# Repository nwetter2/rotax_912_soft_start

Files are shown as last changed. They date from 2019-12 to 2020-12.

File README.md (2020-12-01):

# rotax_912_soft_start
Soft start ignition module for Rotax 900 series engines

All parts [listed in BOM](https://github.com/nwetter2/rotax_912_soft_start/blob/master/BOM.pdf).

Older versions of the Rotax 900 series engines are prone to kickback on starting, which is violent and damaging to the engine. This project, inspired by a similar project by [Turbo-Tom at Rotary Wing Forums](https://www.rotaryforum.com/threads/soft-start-unit-for-rotax-912uls.23381/), improves the issue by ensuring retarded timings are used during start. It accomplishes this by using a relay to introduce a diode in parallel with the timing coil, which filters out the advanced timing pulse, which is opposite the polarity of the retarded timing pulse. Note that Turbo-Tom's design introduces the diode in series with the coil, and this did not work in testing by this project.

The design is quite simple and uses through-hole components to ease construction. It uses the same connectors as the Rotax ignition system, so one can simply unplug one ignition module and insert the soft start module between it and the timing coils. Then, the disable wire of the opposite ignition module is connected, allowing the unmodified ignition circuit to be disabled during start. The mod is also connected to the starter relay and this is what engages the relays during start. A capacitor keeps the relays engaged for 3-8 seconds after starting. Lastly, there is an optional connection for an external indicator, which will be connected to ground while the module is active and left floating when not.

The enclosure is bolted to the top of the existing ignition modules, using longer M5 bolts and washers. The enclosure needs to be modified to accept the larger diameter bolts, and holes added for the wires to pass through. It is recommended to waterproof the pcb after assembly, using the silicone conformal coat listed in the BOM. Loctite 221 or 222 should be used on the mounting bolts.

## Schematic

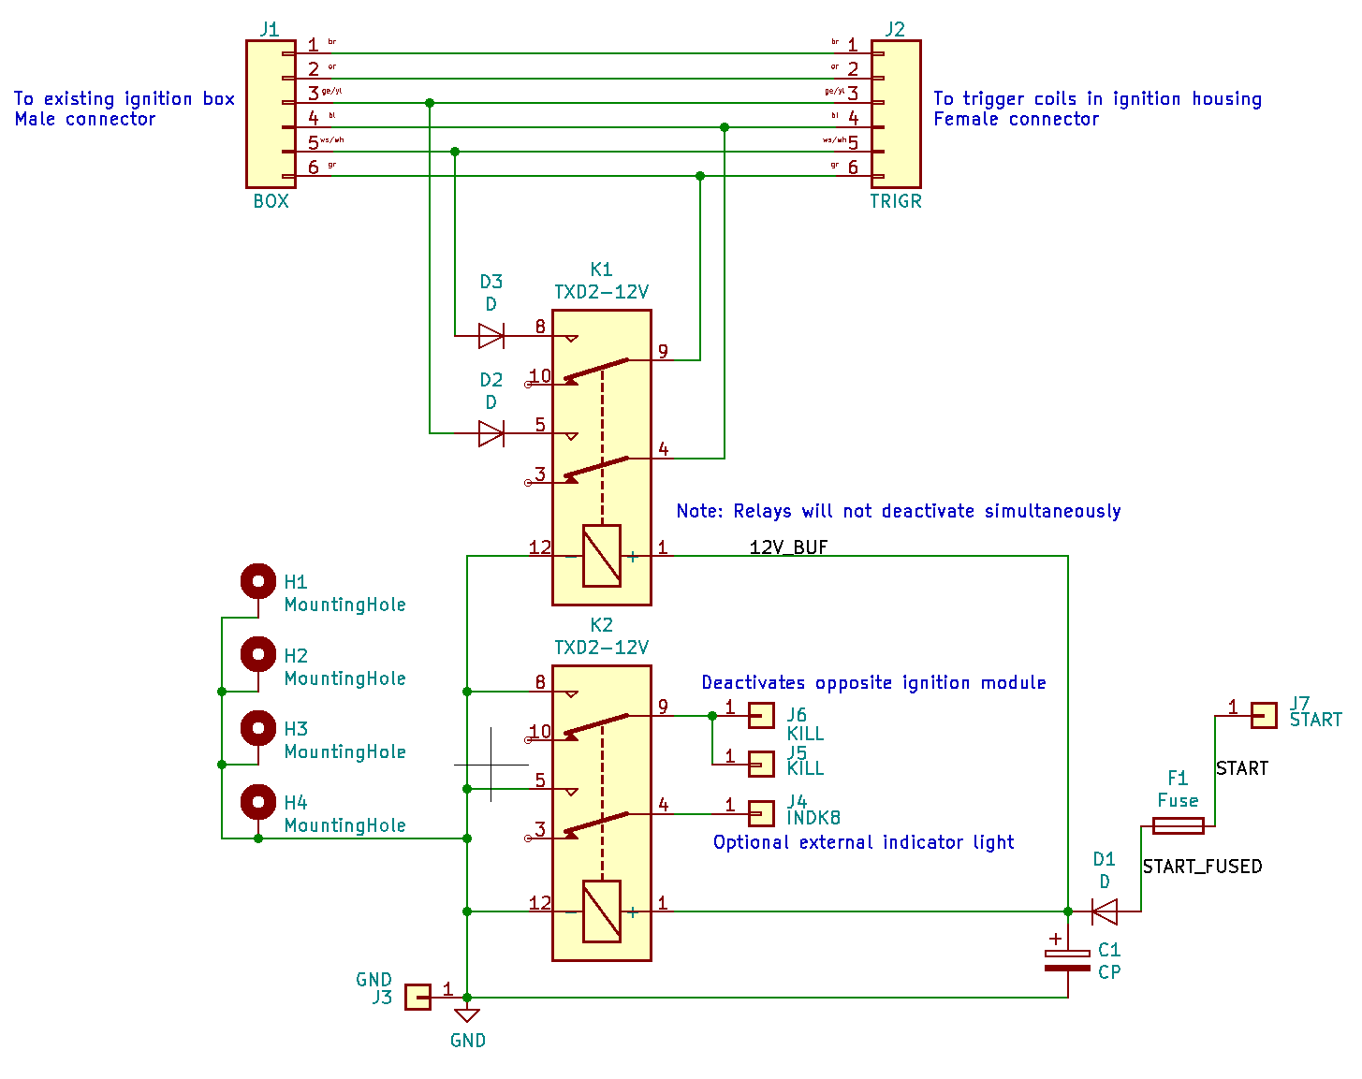
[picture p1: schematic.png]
schematic


## Front

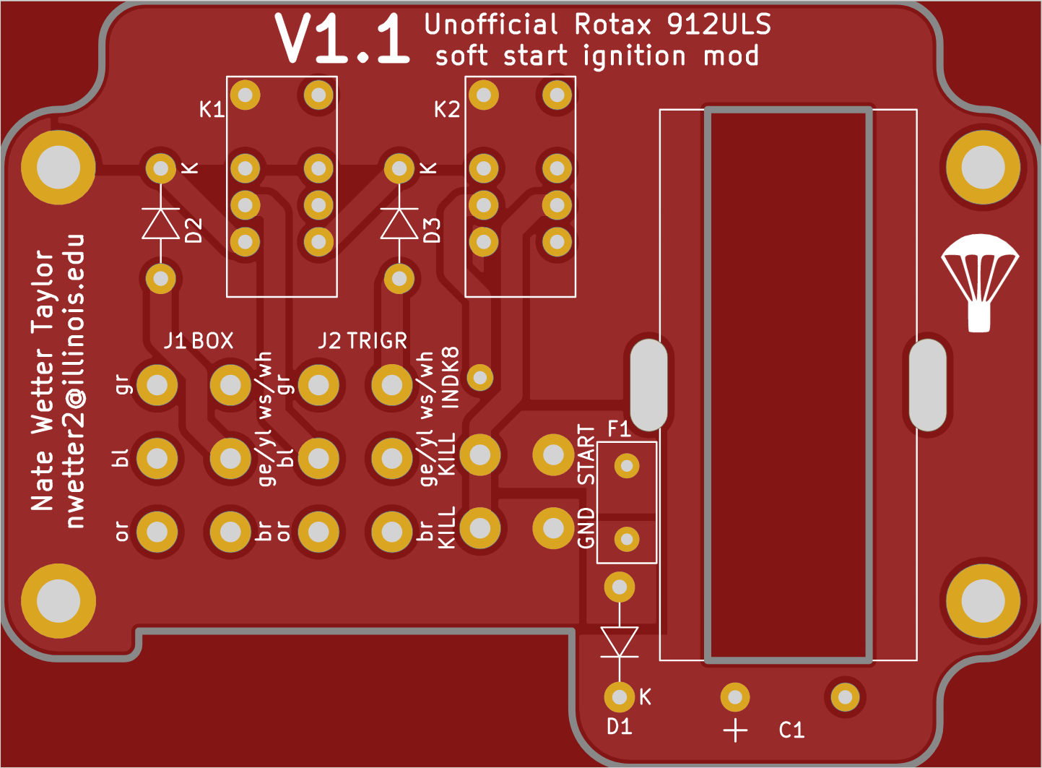
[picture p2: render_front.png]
front


## Back

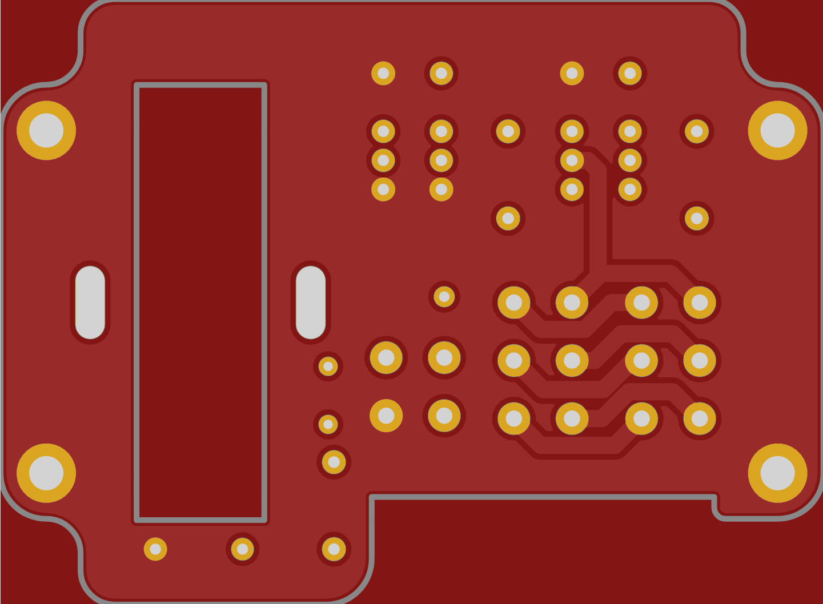
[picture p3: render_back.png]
back


## Assembled
V1.0; no cover

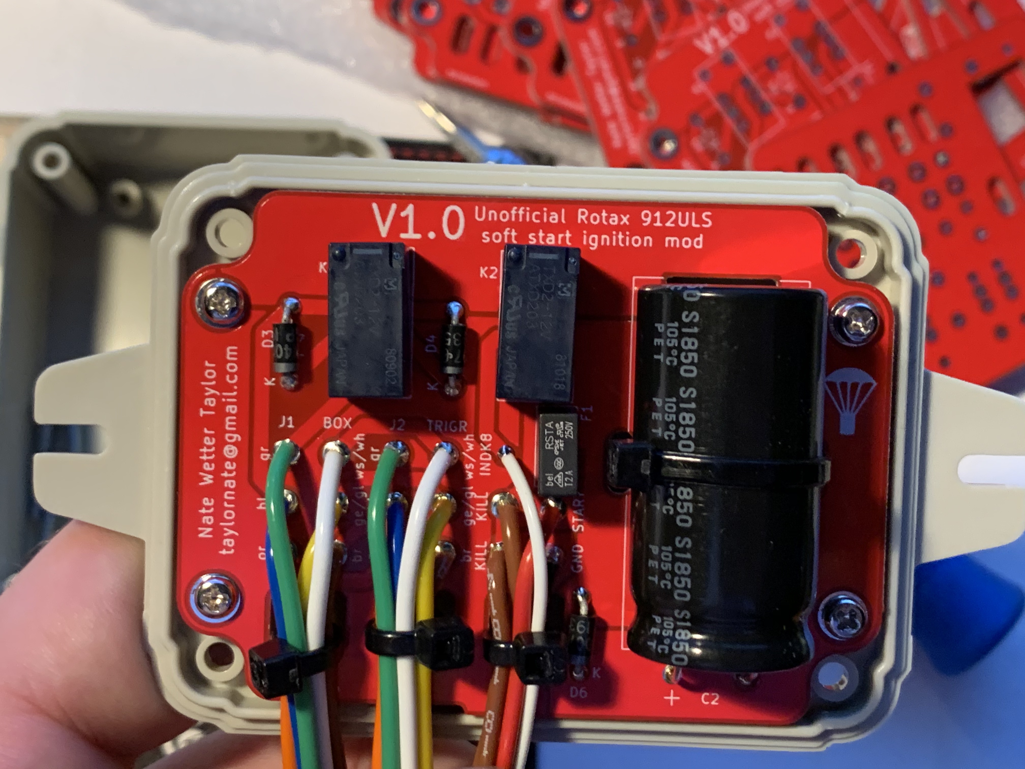
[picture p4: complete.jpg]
assembled


# Installed
V1.0; no cover

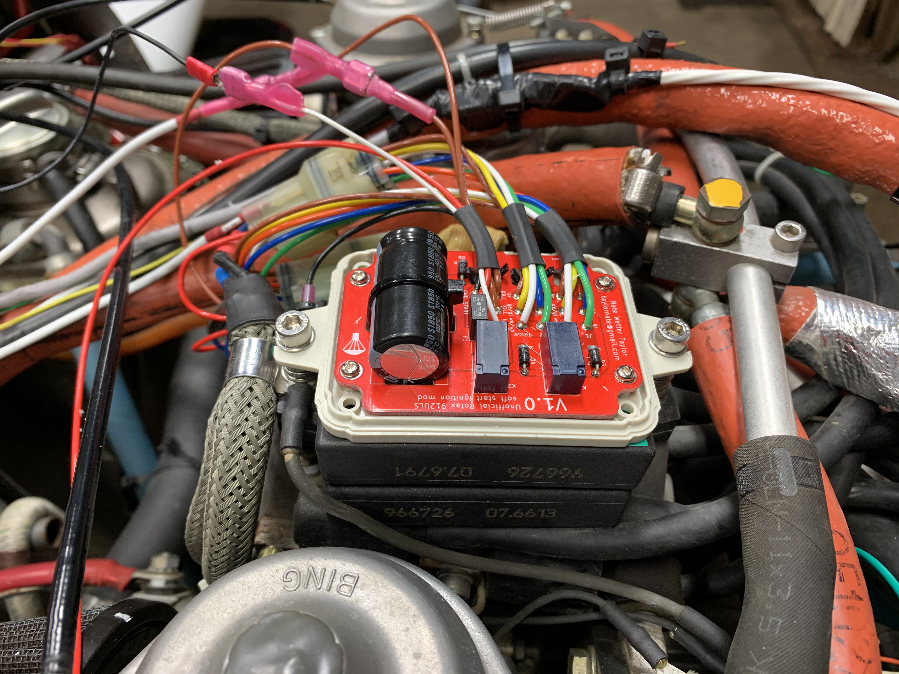
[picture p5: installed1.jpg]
installed


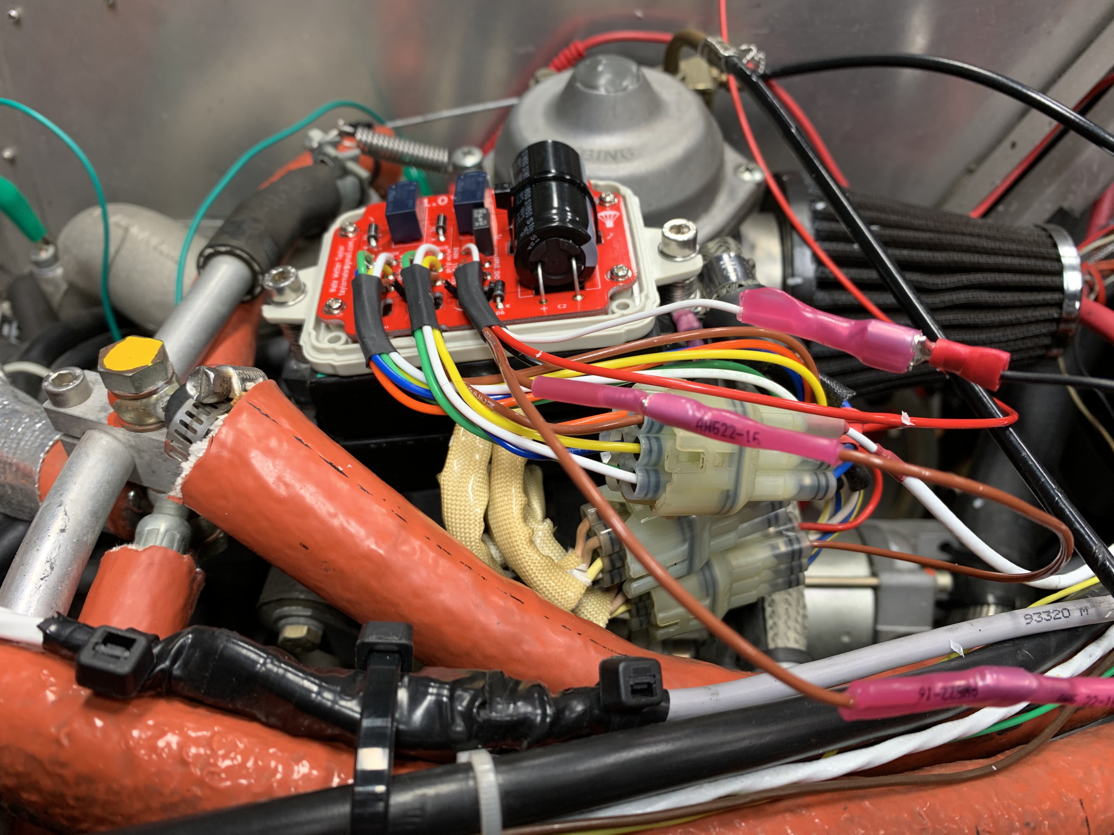
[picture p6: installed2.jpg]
installed


# Before
Signal from the timing coil with the soft start module unengaged

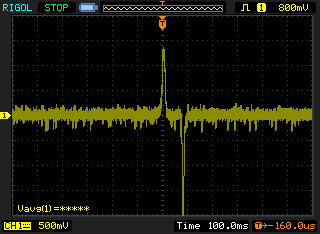
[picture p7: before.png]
before


# After
Signal from the timing coil with the soft start module engaged

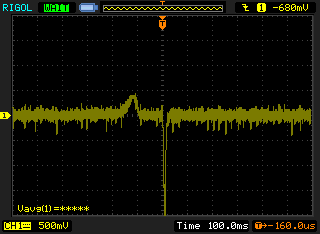
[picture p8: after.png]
after


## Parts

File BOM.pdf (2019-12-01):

Description | Manufacturer | MPN | Quantity Price | price total | URL DPDT relay | Panasonic | TXD2-12V | 2 | 4.61 | 9.22 https://www.digikey.com/product-detail/en/panasonic-electric-works/TXD2-12V/255-2320-5-ND/649875
diode | Vishay | 1N4007GP-E3/54 | 3 | 0.38 | 1.14 https://www.digikey.com/product-detail/en/vishay-semiconductor-diodes-division/1N4007GP-E3-54/1N4007GP-E3-54GICT-ND/3025818
capacitor | Panasonic | 25PX10000MEFC18X35.5 | 1 | 2.45 | 2.45 https://www.digikey.com/product-detail/en/rubycon/25PX10000MEFC18X35.5/1189-1223-ND/3134179
fuse | Bel Fuse | RSTA 2 BULK | 1 | 0.29 | 0.29 https://www.digikey.com/product-detail/en/RSTA+2+BULK/507-1859-ND/4968135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
connector, female | Aftermarket Sumimoto | HM-6S | 1 | 2.17 | 2.17 https://www.corsa-technic.com/item.php?item_id=625
connector, male | Aftermarket Sumimoto | HM-6P | 1 | 3.8 | 3.8 https://www.corsa-technic.com/item.php?item_id=343
enclosure | Hammond Manufacturing RL6105-F | 1 | 3.39 | 3.39 https://www.digikey.com/product-detail/en/RL6105-F/HM5721-ND/2570558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
conformal coat | 18.82 https://www.amazon.com/gp/product/B008O9YIV6/ref=ppx_yo_dt_b_asin_title_o00_s00?ie=UTF8&psc=1 wires bolts 5x40mm | 7.01 https://www.mcmaster.com/91292a194 washers | 2.57 https://www.mcmaster.com/93475a240 PCB
total | 50.86

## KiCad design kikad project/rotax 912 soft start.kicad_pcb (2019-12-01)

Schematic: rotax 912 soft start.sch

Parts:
C1: CP; cap
D1, D2, D3: D; diode
F1: Fuse; fuse
H1, H2, H3, H4: MountingHole; mounting_hole
J1: BOX; 6_wire_18awg
J2: TRIGR; 6_wire_18awg
J3: GND; wire_18awg_stranded
J4: INDK8; wire_22awg_stranded
J5, J6: KILL; wire_18awg_stranded
J7: START; wire_18awg_stranded
K1, K2: TXD2-12V; Relay_TXD2-12V

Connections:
/12V_BUF: C1.1, D1.1 (K), K1.1 (+), K2.1 (+)
/START: F1.1, J7.1
/START_FUSED: D1.2 (A), F1.2
GND: C1.2, H1.1, H2.1, H3.1, H4.1, J3.1, K1.12 (-), K2.5, K2.8, K2.12 (-)
unnamed: D2.1 (K), K1.5
unnamed: D2.2 (A), J1.3, J2.3
unnamed: D3.1 (K), K1.8
unnamed: D3.2 (A), J1.5, J2.5
unnamed: J1.1, J2.1
unnamed: J1.2, J2.2
unnamed: J1.4, J2.4, K1.4
unnamed: J1.6, J2.6, K1.9
unnamed: J4.1, K2.4
unnamed: J5.1, J6.1, K2.9

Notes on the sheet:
To trigger coils in ignition housing Female connector
To existing ignition box Male connector
Deactivates opposite ignition module
Optional external indicator light
Note: Relays will not deactivate simultaneously

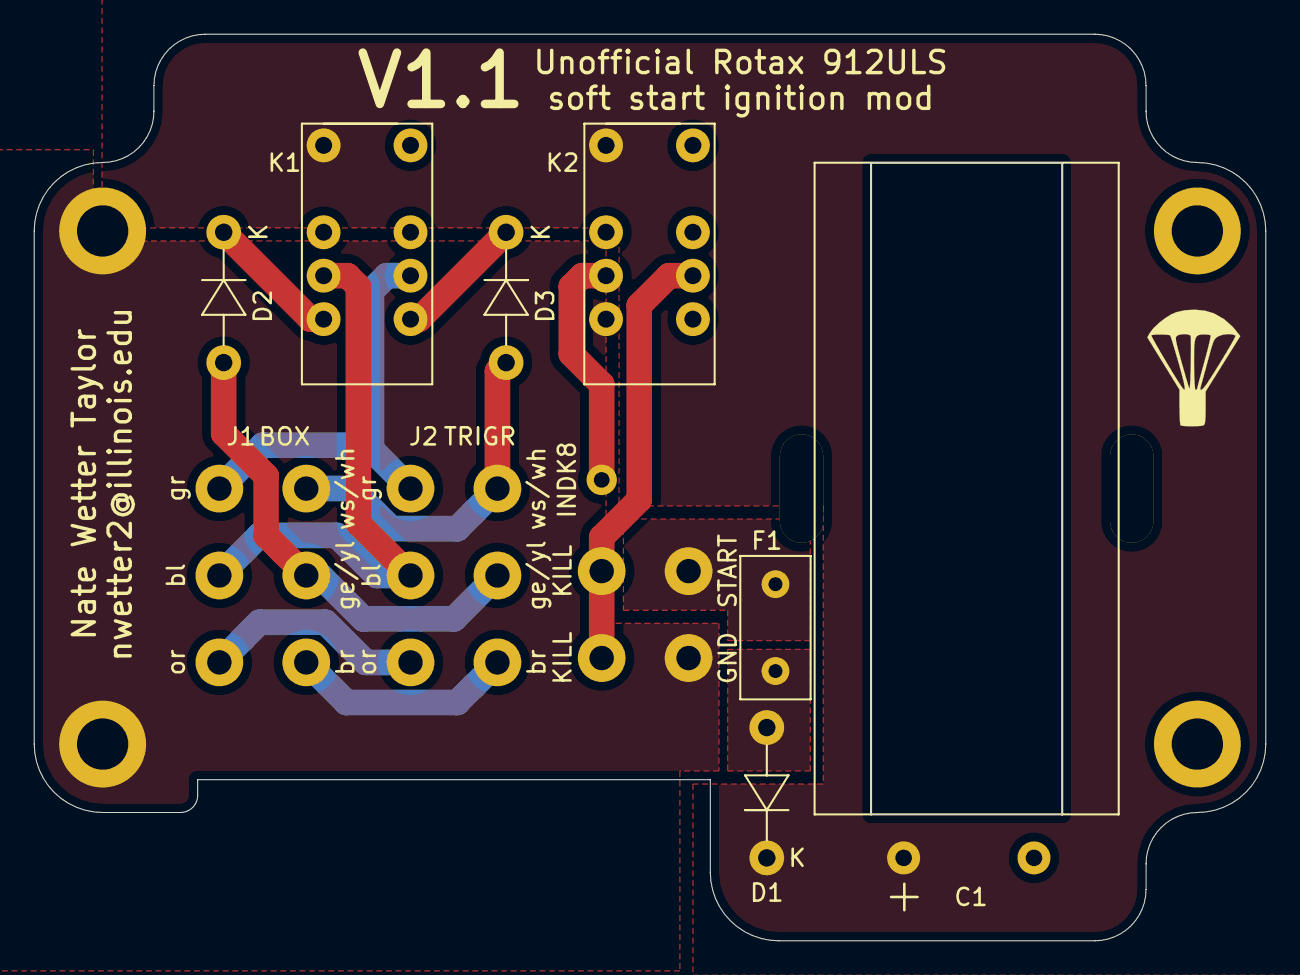
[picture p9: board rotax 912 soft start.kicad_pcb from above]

Board: 2 copper layers, 72.0 x 53.0 mm, 18 parts (0 on the bottom side), 14 nets.
